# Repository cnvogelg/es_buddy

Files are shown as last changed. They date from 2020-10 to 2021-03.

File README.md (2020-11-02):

# es_buddy - EuroShield Add On Boards

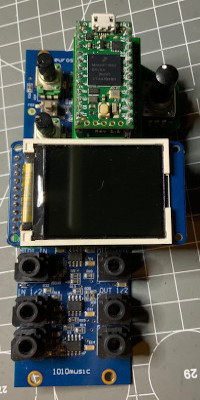
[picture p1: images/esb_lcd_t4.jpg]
esb_lcd_t4 Teensy 4.0 with LCD
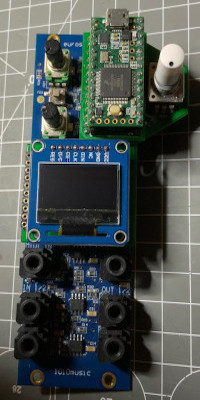
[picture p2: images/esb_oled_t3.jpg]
esb_oled_t3 Teensy 3.2 with OLED
 

EuroShield Buddy PCB Boards and Arduino Library.

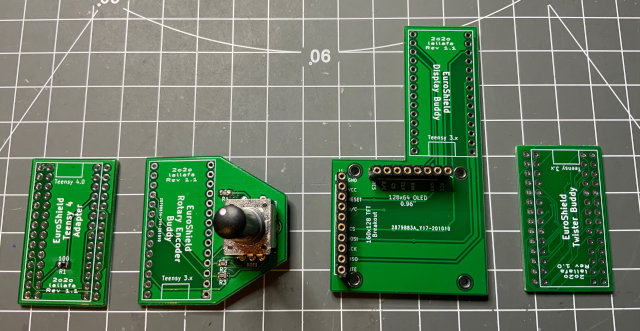
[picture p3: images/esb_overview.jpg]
esb_overview The ES Buddy Board Gallery


  - [Teensy 4.0 Adapter](#teensy-40-adapter)
  - [Rotary Encoder Buddy Board](#rotary-encoder-buddy-board)
  - [LCD/OLED Display Buddy Board](#lcdoled-display-buddy-board)
  - [Twister Buddy Board](#twister-buddy-board)

You can combine these boards as you like.

Licensed by Creative Commons Attribution Share Alike 4.0 International

## Teensy 4.0 Adapter

Version: 1.1

This little adapter board allows to use a Teensy 4.0 board on your EuroShield 1 (short ES) eurorack module.

This is the required re-routing of the Pins:

| Teensy 3.x / EuroShield Pin | Teensy 4.x Pin | Description |
|---|---|---|
| GND | GND | |
| 0 | 0 | Midi IN |
| 1 | 1 | Midi Out |
| 2 | 2 | Button on ES and on Rotary Encoder |
| 3 | 3 | LED 1 |
| 4 | 4 | LED 2 |
| 5 | 5 | LED 2 |
| 6 | 6 | LED 3 |
| 7 | 11 | SPI MOSI |
| 8 | 9 | Display Reset |
| 9 | 21 | Audio BCLK |
| 10 | 10 | SPI CS |
| 11 | 23 | Audio MCLK - A 100 Ohm Resistor is required here! |
| 12 | 12 | SPI MISO |

| Teensy 3.x / EuroShield Pin | Teensy 4.x Pin | Description |
|---|---|---|
| VIN | VIN | |
| AGND | AGND | |
| 3.3V | 3.3V | |
| 23 | 20 | Audio LRCLK |
| 22 | 7 | Audio TX DIN |
| 21 | 15 | Lo Pot on ES |
| 20 | 14 | Hi Pot on ES |
| 19 | 19 | I2C SCL |
| 18 | 18 | I2C SDA |
| 17 | 17 | Rotary Encoder A |
| 16 | 16 | Rotary Encoder B |
| 15 | 22 | Display CMD/Data |
| 14 | 13 | SPI SCK |
| 13 | 8 | Audio RX DOUT |

All Pins are direclty connected expect Audio MCLK is connected via
a 100 Ohm resistor.

## Rotary Encoder Buddy Board

Version: 1.1

Add a rotary encoder with button to your Euroshield.

### BOM

| Symbol | Part | Description | Mouser No. |
|---|---|---|---|
| ROT1 | PEC12R-3220F-S0024 | Bourns Rotary Encoder | 652-PEC12R3220FS0024 |
| R1-R3 | SMD 0805 10k | 10k Resistor | 71-CRCW080510K0FKEAC |

## LCD/OLED Display Buddy Board

Version: 1.1

Add an SPI LCD or OLED display to your EuroShield. While the OLED with 
128 x 64 fits nicely into the form factor of the shield, the LCD is wider
and offers 160 x 128 colored pixels.

The LCD has the following parameters:

 - 160 x 128 color TFT LCD 1.8 Inch
 - SPI
 - ST 7735 Controller

| LCD Pin | Teensy 3.2 Pin | Description |
| --- | --- | --- |
| 1 | GND | GND |
| 2 | 3.3V | 3.3V |
| 3 | 8  | Display Reset |
| 4 | 15 | Display Cmd/Data |
| 5 | -  | N/A |
| 6 | 10 | SPI CS |
| 7 | 7  | SPI MOSI |
| 8 | 14 | SPI SCK |
| 9 | 12 | SPI MISO |
| 10 | 3.3V | Display Light |

I use an Adafruit 1.8" Color TFT LCD display with MicroSD Card Breakout (358)

The OLED has the following parameters:

- 128 x 64 monochrome OLED 0.96 Inch
- SPI
- SSD 1306 Controller

| OLED Pin | Teensy 3.2 Pin | Description |
| --- | --- | --- |
| 1 | 3.3V | 3.3V |
| 2 | GND | GND |
| 3 | -  | N/A|
| 4 | 7  | SPI MOSI |
| 5 | 14 | SPI SCK |
| 6 | 10 | SPI CS |
| 7 | 15 | Display Cmd/Data |
| 8 | 8  | Display Reset |

## Twister Buddy Board

Version: 1.0

Turn the Teensy around so that the USB connector points upwards and 
a connected USB cable gets out of the way and does not obstruct the display.

# Build Instructions

If you want to build the full stack of buddy boards:

1. Start with the display board and solder extra long header pins

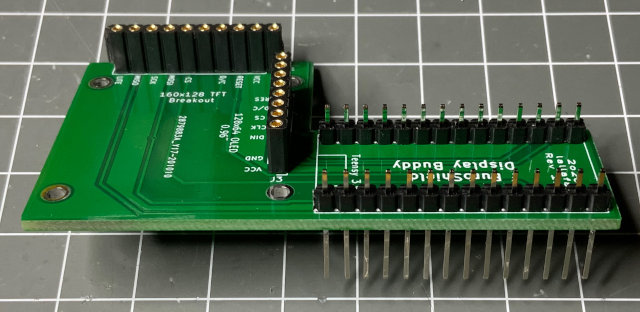
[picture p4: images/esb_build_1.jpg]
esb_build_1 Start with Display
  

2. First populate the rotary encoder board (resistors and the encoder) and 
  then solder the board below the display board

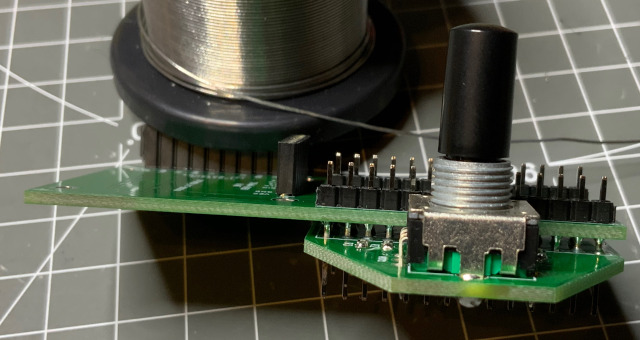
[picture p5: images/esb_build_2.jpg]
esb_build_2 Stack Rotary Encoder below
  

3. Prepare the Twister Board by adding headers to one side for a Teensy 4.0
  setup or a female connector for a Teensy 3.2. If you want to 
  use a Teensy 4.0 then add a female connector to the Teensy 4.0 side of the
  adapter:

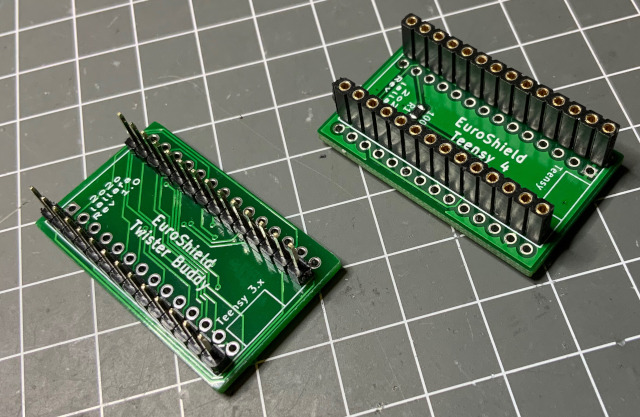
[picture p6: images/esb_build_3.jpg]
esb_build_3 Stack Rotary Encoder below
  

4. Solder the prepared Twister Board on top of the Display Board. Make sure
  that the Teensy USB port on the top side points upwards:

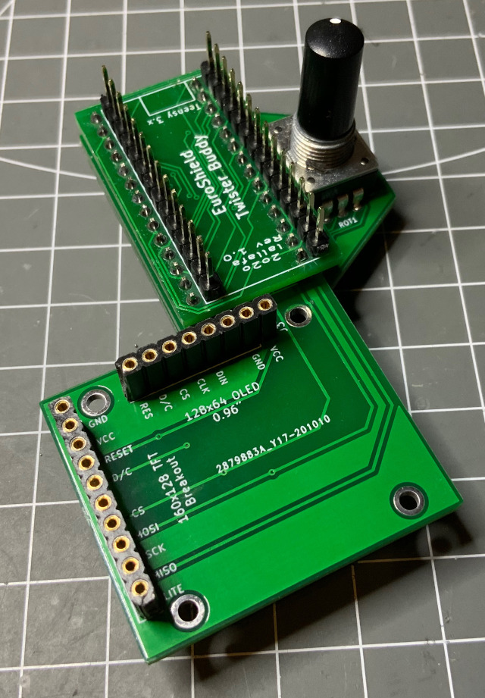
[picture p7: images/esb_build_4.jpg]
esb_build_4 Add Twister Board
  

5. For a Teensy 4.0 finally solder the Teensy 4.0 adapter board on top of
  the Twister Board. Note: make sure to add some space between the boards
  so that the Teensy 4.0 female connector pins do not touch the Display
  Board pins! Here a both variants: Teensy 4.0 and Teensy 3.2 boards

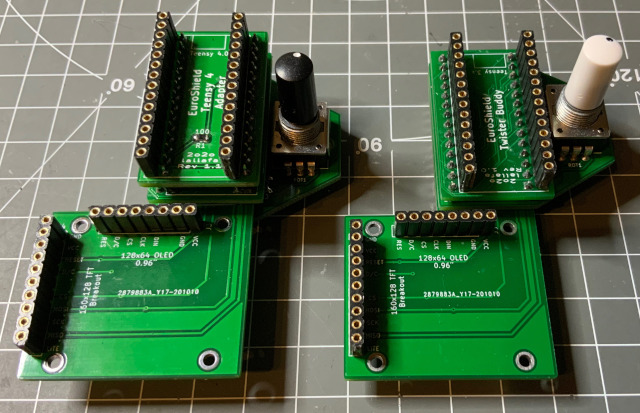
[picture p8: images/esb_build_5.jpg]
esb_build_5 Both Teensy 4.0 and Teensy 3.2 Board
  

6. Finally add either a LCD or OLED display. Both display types work with 
  both Teensy CPUs.

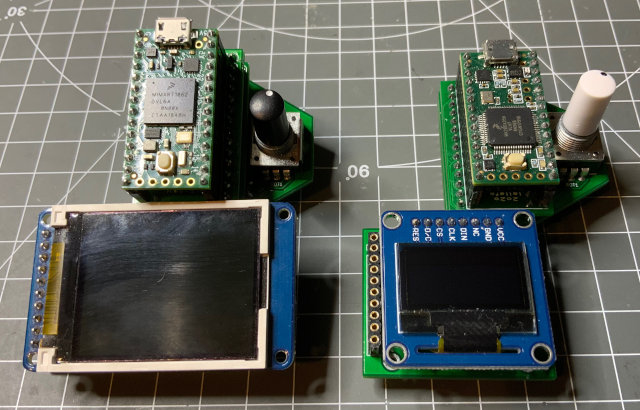
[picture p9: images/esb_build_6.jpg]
esb_build_6 Add LCD or OLED Display


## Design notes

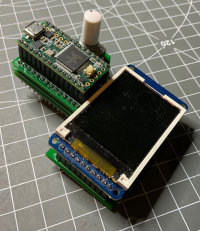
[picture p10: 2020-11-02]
images/esb_lcd_t3.jpg

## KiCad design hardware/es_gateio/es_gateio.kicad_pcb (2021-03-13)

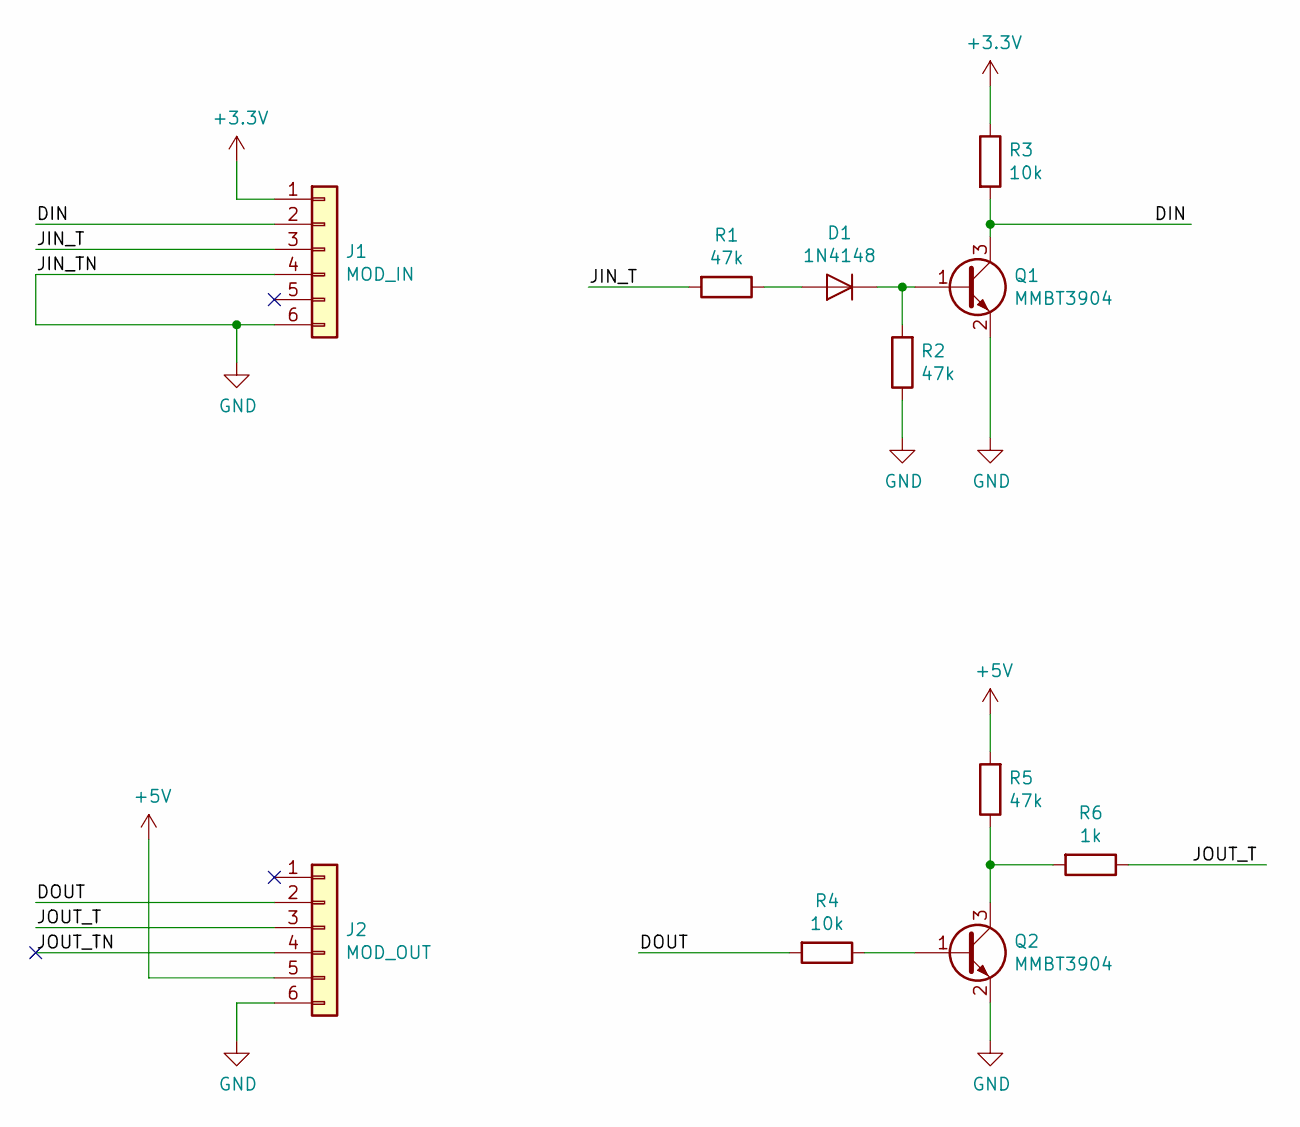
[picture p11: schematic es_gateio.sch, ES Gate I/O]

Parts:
D1: 1N4148; D_MiniMELF
J1: MOD_IN; PinHeader_2x03_P2.54mm_Vertical
J2: MOD_OUT; PinHeader_2x03_P2.54mm_Vertical
Q1, Q2: MMBT3904; SOT-23
R1, R2, R5: 47k; R_0805_2012Metric_Pad1.15x1.40mm_HandSolder
R3, R4: 10k; R_0805_2012Metric_Pad1.15x1.40mm_HandSolder
R6: 1k; R_0805_2012Metric_Pad1.15x1.40mm_HandSolder

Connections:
+3V3: J1.1, R3.1
+5V: J2.5, R5.2
/DIN: J1.2, Q1.3 (C), R3.2
/DOUT: J2.2, R4.2
/JIN_T: J1.3, R1.2
/JOUT_T: J2.3, R6.1
/JOUT_TN: J2.4
GND: J1.4, J1.6, J2.6, Q1.2 (E), Q2.2 (E), R2.1
unnamed: D1.1 (K), Q1.1 (B), R2.2
unnamed: D1.2 (A), R1.1
unnamed: Q2.1 (B), R4.1
unnamed: Q2.3 (C), R5.1, R6.2

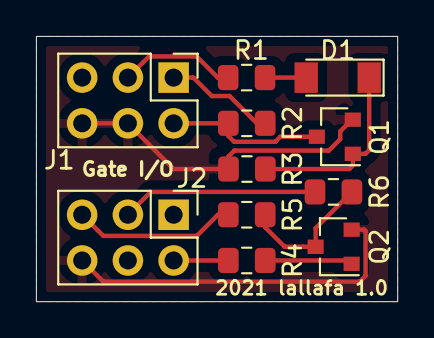
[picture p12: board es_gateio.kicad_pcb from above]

Board: 2 copper layers, 20.1 x 14.7 mm, 11 parts (0 on the bottom side), 11 nets.

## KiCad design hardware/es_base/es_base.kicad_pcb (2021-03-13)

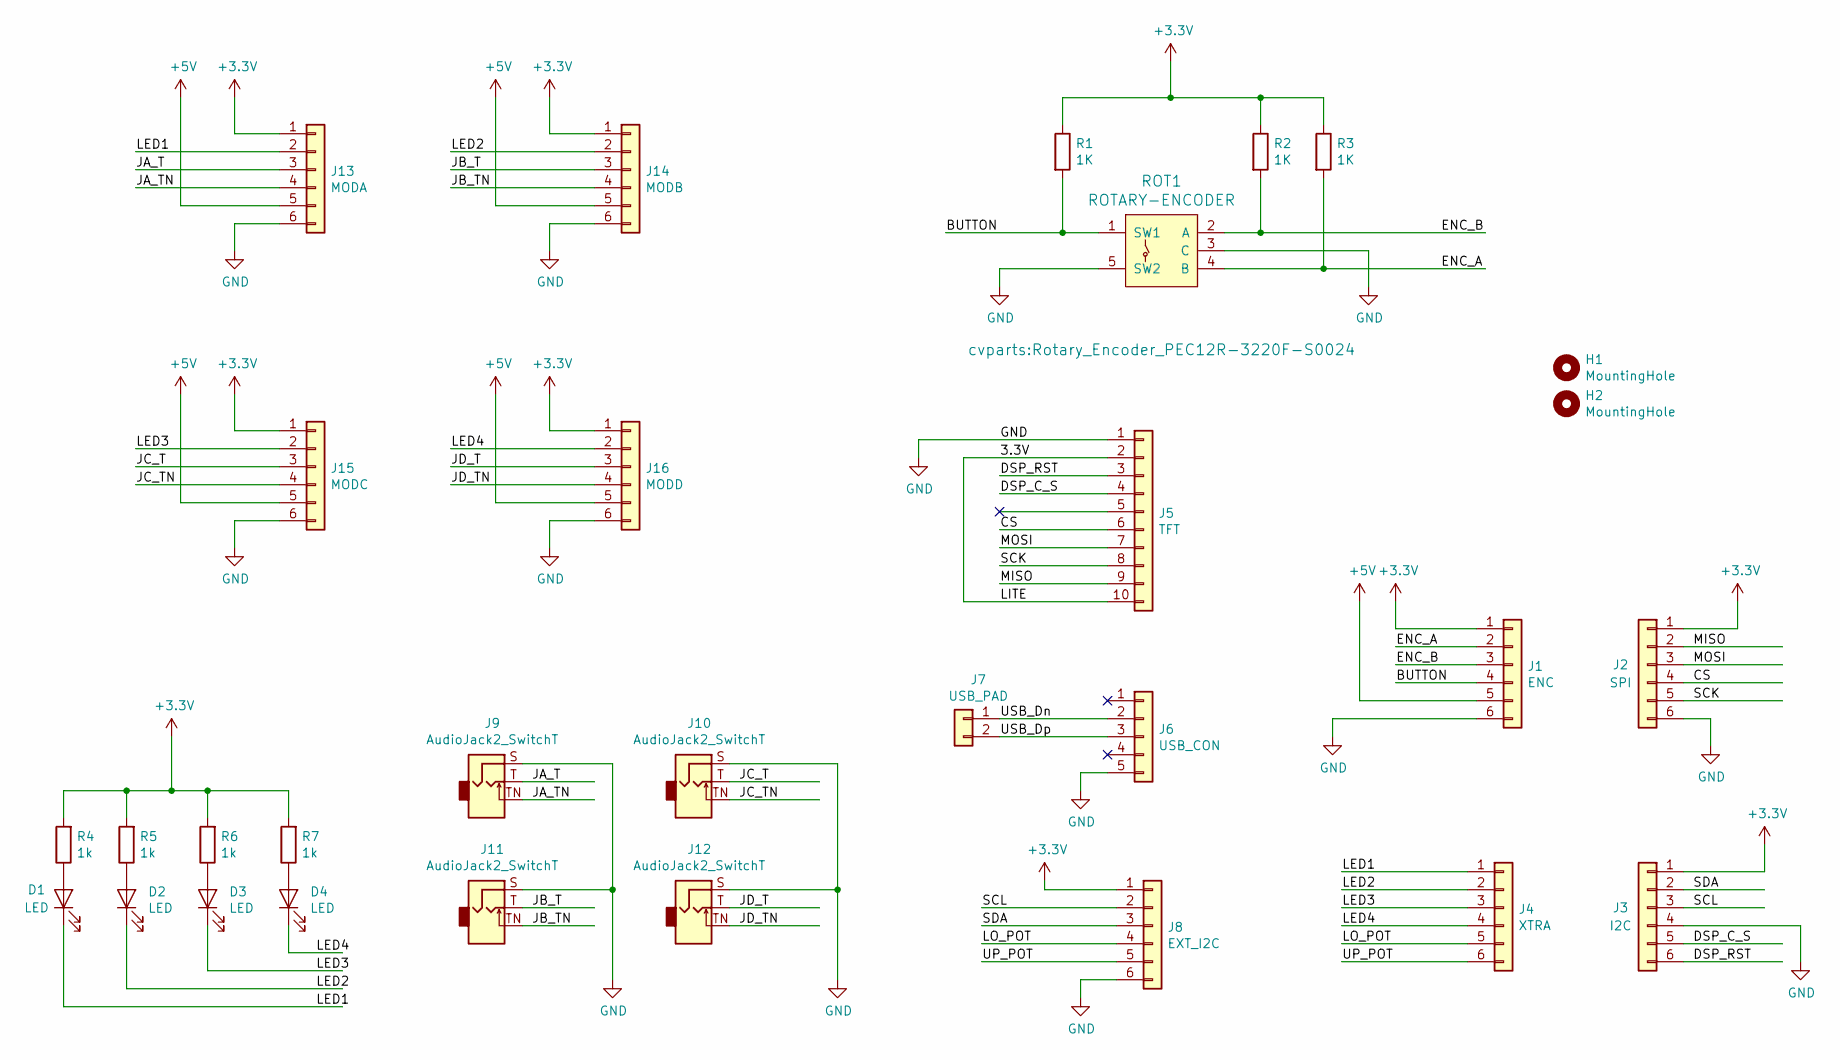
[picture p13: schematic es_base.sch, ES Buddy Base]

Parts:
D1, D2, D3, D4: LED; LED_D3.0mm
H1, H2: MountingHole; MountingHole_3.2mm_M3_ISO14580_Pad
J1: ENC; PinHeader_1x06_P2.54mm_Vertical
J2: SPI; PinHeader_1x06_P2.54mm_Vertical
J3: I2C; PinHeader_1x06_P2.54mm_Vertical
J4: XTRA; PinHeader_1x06_P2.54mm_Vertical
J5: TFT; PinHeader_1x10_P2.54mm_Vertical
J6: USB_CON; PinHeader_1x05_P2.54mm_Vertical
J7: USB_PAD; PinHeader_1x02_P2.54mm_Vertical
J8: EXT_I2C; PinHeader_2x03_P2.54mm_Vertical
J9, J10, J11, J12: AudioJack2_SwitchT; Jack_3.5mm_QingPu_WQP-PJ398SM_Vertical_CircularHoles
J13: MODA; PinHeader_2x03_P2.54mm_Vertical
J14: MODB; PinHeader_2x03_P2.54mm_Vertical
J15: MODC; PinHeader_2x03_P2.54mm_Vertical
J16: MODD; PinHeader_2x03_P2.54mm_Vertical
R1, R2, R3: 1K; R_0805_2012Metric_Pad1.15x1.40mm_HandSolder
R4, R5, R6, R7: 1k; R_0805_2012Metric_Pad1.15x1.40mm_HandSolder
ROT1: ROTARY-ENCODER; Rotary_Encoder_PEC12R-3220F-S0024

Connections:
+3V3: J1.1, J2.1, J3.1, J8.1, J13.1, J14.1, J15.1, J16.1, R1.1, R2.1, R3.1, R4.2, R5.2, R6.2, R7.2
+5V: J1.5, J13.5, J14.5, J15.5, J16.5
/3.3V: J5.2, J5.10
/BUTTON: J1.4, R1.2, ROT1.1 (SW1)
/CS: J2.4, J5.6
/DSP_C_S: J3.5, J5.4
/DSP_RST: J3.6, J5.3
/ENC_A: J1.2, R3.2, ROT1.4 (B)
/ENC_B: J1.3, R2.2, ROT1.2 (A)
/JA_T: J9.T, J13.3
/JA_TN: J9.TN, J13.4
/JB_T: J11.T, J14.3
/JB_TN: J11.TN, J14.4
/JC_T: J10.T, J15.3
/JC_TN: J10.TN, J15.4
/JD_T: J12.T, J16.3
/JD_TN: J12.TN, J16.4
/LED1: D1.1 (K), J4.1, J13.2
/LED2: D2.1 (K), J4.2, J14.2
/LED3: D3.1 (K), J4.3, J15.2
/LED4: D4.1 (K), J4.4, J16.2
/LO_POT: J4.5, J8.4
/MISO: J2.2, J5.9
/MOSI: J2.3, J5.7
/SCK: J2.5, J5.8
/SCL: J3.3, J8.2
/SDA: J3.2, J8.3
/UP_POT: J4.6, J8.5
/USB_Dn: J6.2, J7.1
/USB_Dp: J6.3, J7.2
GND: J1.6, J2.6, J3.4, J5.1, J6.5, J8.6, J9.S, J10.S, J11.S, J12.S, J13.6, J14.6, J15.6, J16.6, ROT1.3 (C), ROT1.5 (SW2)
unnamed: D1.2 (A), R4.1
unnamed: D2.2 (A), R5.1
unnamed: D3.2 (A), R6.1
unnamed: D4.2 (A), R7.1

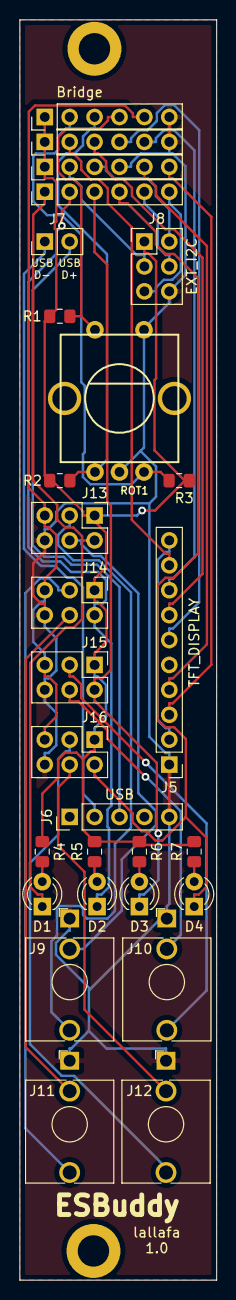
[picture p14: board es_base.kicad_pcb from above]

Board: 2 copper layers, 20.1 x 128.5 mm, 30 parts (0 on the bottom side), 35 nets.

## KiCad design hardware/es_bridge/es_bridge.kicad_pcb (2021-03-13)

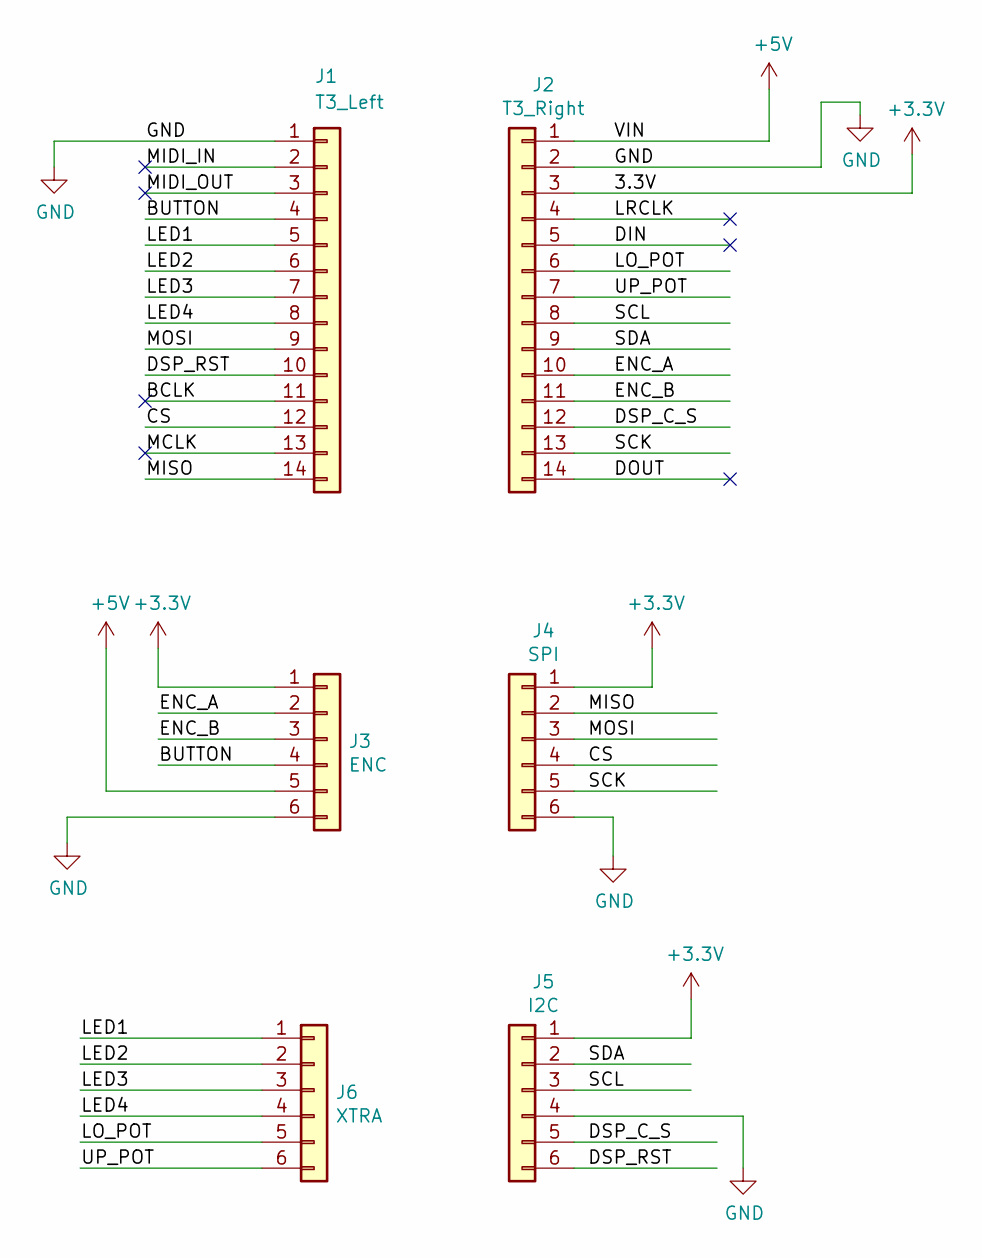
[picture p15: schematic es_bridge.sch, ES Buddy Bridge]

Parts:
J1: T3_Left; PinHeader_1x14_P2.54mm_Vertical_NoSilk
J2: T3_Right; PinHeader_1x14_P2.54mm_Vertical_NoSilk_NoPin1
J3: ENC; PinHeader_1x06_P2.54mm_Vertical
J4: SPI; PinHeader_1x06_P2.54mm_Vertical
J5: I2C; PinHeader_1x06_P2.54mm_Vertical
J6: XTRA; PinHeader_1x06_P2.54mm_Vertical

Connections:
+3V3: J2.3, J3.1, J4.1, J5.1
+5V: J2.1, J3.5
/BCLK: J1.11
/BUTTON: J1.4, J3.4
/CS: J1.12, J4.4
/DIN: J2.5
/DOUT: J2.14
/DSP_C_S: J2.12, J5.5
/DSP_RST: J1.10, J5.6
/ENC_A: J2.10, J3.2
/ENC_B: J2.11, J3.3
/LED1: J1.5, J6.1
/LED2: J1.6, J6.2
/LED3: J1.7, J6.3
/LED4: J1.8, J6.4
/LO_POT: J2.6, J6.5
/LRCLK: J2.4
/MCLK: J1.13
/MIDI_IN: J1.2
/MIDI_OUT: J1.3
/MISO: J1.14, J4.2
/MOSI: J1.9, J4.3
/SCK: J2.13, J4.5
/SCL: J2.8, J5.3
/SDA: J2.9, J5.2
/UP_POT: J2.7, J6.6
GND: J1.1, J2.2, J3.6, J4.6, J5.4

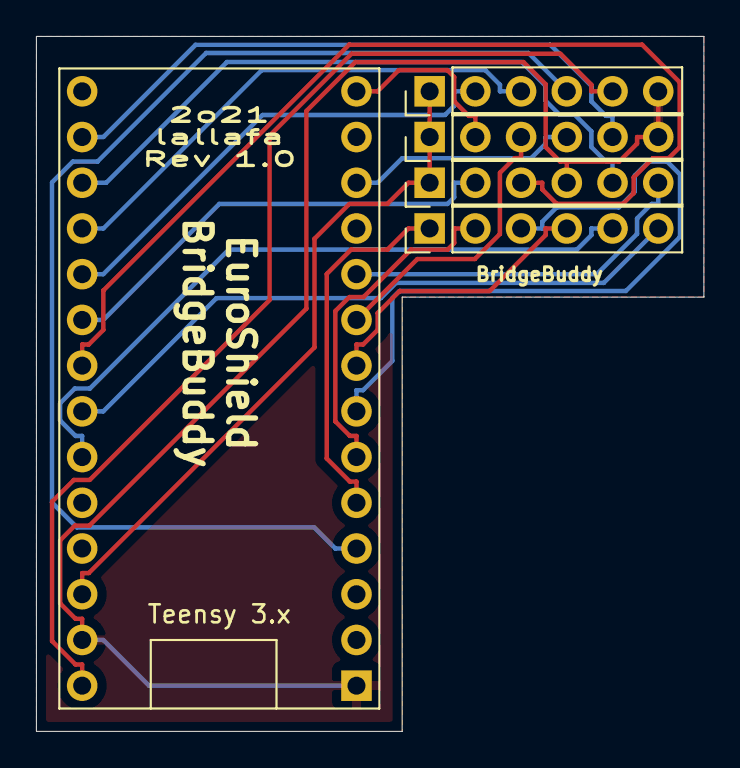
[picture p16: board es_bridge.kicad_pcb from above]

Board: 2 copper layers, 37.1 x 38.6 mm, 6 parts (0 on the bottom side), 20 nets.

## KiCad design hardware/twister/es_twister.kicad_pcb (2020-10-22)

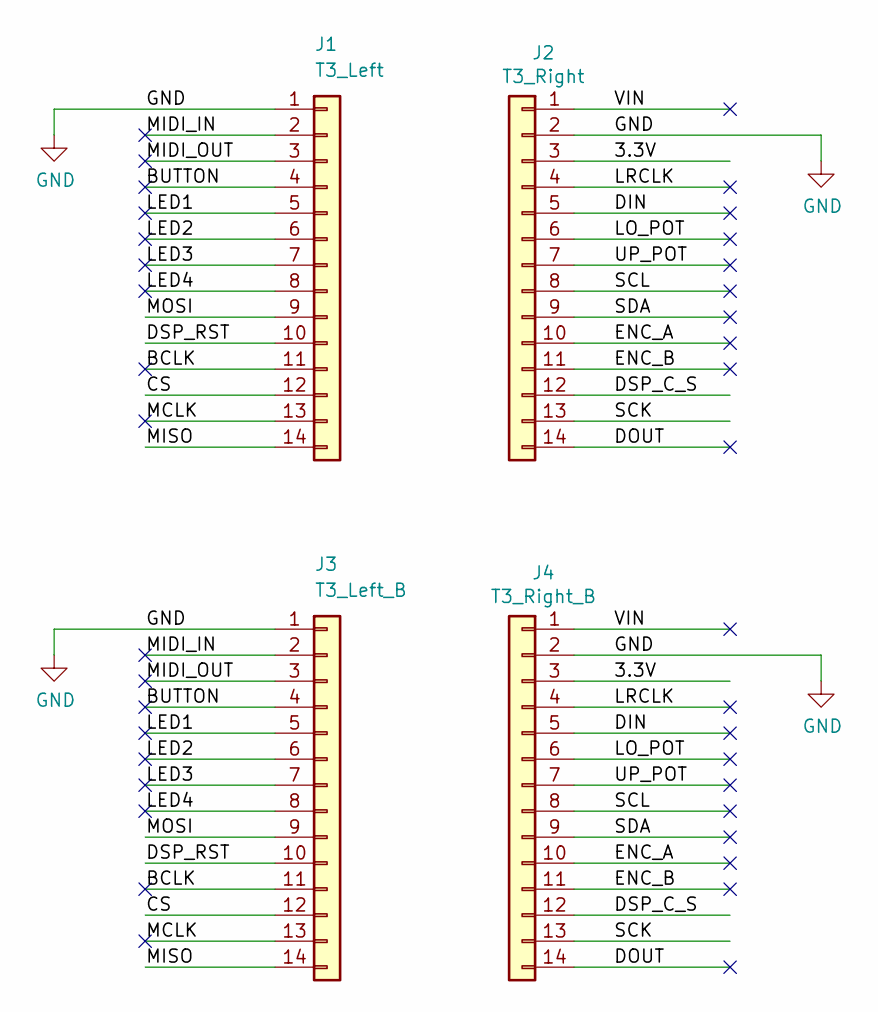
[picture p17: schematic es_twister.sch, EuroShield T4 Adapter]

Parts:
J1: T3_Left; PinHeader_1x14_P2.54mm_Vertical_NoSilk
J2: T3_Right; PinHeader_1x14_P2.54mm_Vertical_NoSilk_NoPin1
J3: T3_Left_B; PinHeader_1x14_P2.54mm_Vertical_NoSilk
J4: T3_Right_B; PinHeader_1x14_P2.54mm_Vertical_NoSilk_NoPin1

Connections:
/3.3V: J2.3, J4.3
/BCLK: J1.11, J3.11
/BUTTON: J1.4, J3.4
/CS: J1.12, J3.12
/DIN: J2.5, J4.5
/DOUT: J2.14, J4.14
/DSP_C_S: J2.12, J4.12
/DSP_RST: J1.10, J3.10
/ENC_A: J2.10, J4.10
/ENC_B: J2.11, J4.11
/LED1: J1.5, J3.5
/LED2: J1.6, J3.6
/LED3: J1.7, J3.7
/LED4: J1.8, J3.8
/LO_POT: J2.6, J4.6
/LRCLK: J2.4, J4.4
/MCLK: J1.13, J3.13
/MIDI_IN: J1.2, J3.2
/MIDI_OUT: J1.3, J3.3
/MISO: J1.14, J3.14
/MOSI: J1.9, J3.9
/SCK: J2.13, J4.13
/SCL: J2.8, J4.8
/SDA: J2.9, J4.9
/UP_POT: J2.7, J4.7
/VIN: J2.1, J4.1
GND: J1.1, J2.2, J3.1, J4.2

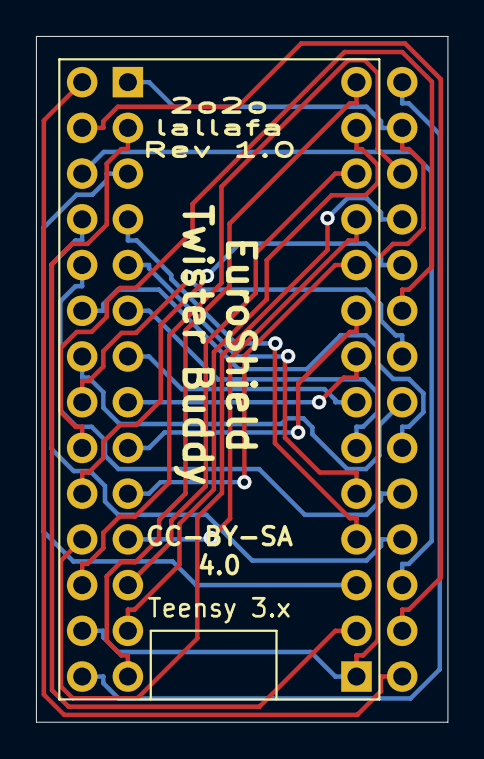
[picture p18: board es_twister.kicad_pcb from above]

Board: 2 copper layers, 22.9 x 38.1 mm, 4 parts (0 on the bottom side), 27 nets.

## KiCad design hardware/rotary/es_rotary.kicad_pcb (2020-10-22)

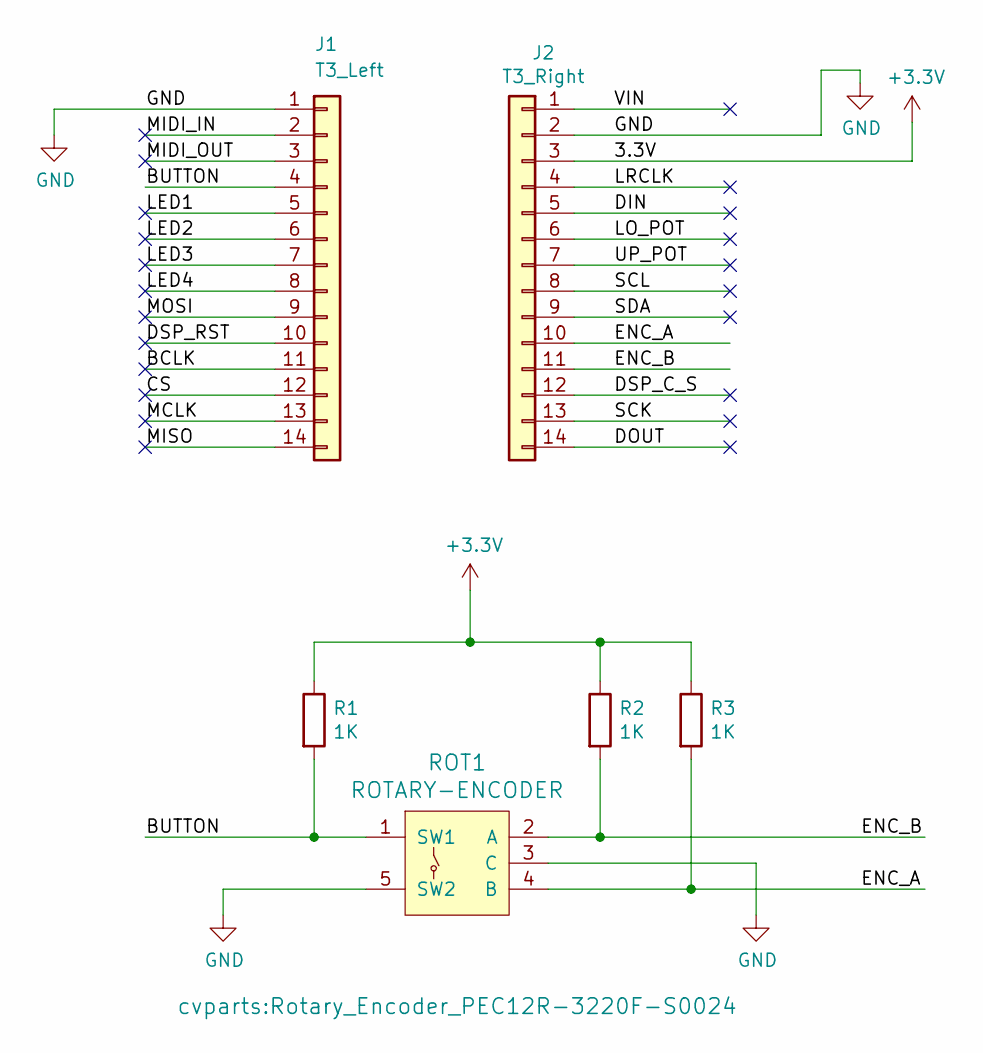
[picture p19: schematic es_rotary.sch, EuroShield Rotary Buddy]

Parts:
J1: T3_Left; PinHeader_1x14_P2.54mm_Vertical_NoSilk
J2: T3_Right; PinHeader_1x14_P2.54mm_Vertical_NoSilk_NoPin1
R1, R2, R3: 1K; R_0805_2012Metric_Pad1.15x1.40mm_HandSolder
ROT1: ROTARY-ENCODER; Rotary_Encoder_PEC12R-3220F-S0024

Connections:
+3V3: J2.3, R1.1, R2.1, R3.1
/BCLK: J1.11
/BUTTON: J1.4, R1.2, ROT1.1 (SW1)
/CS: J1.12
/DIN: J2.5
/DOUT: J2.14
/DSP_C_S: J2.12
/DSP_RST: J1.10
/ENC_A: J2.10, R3.2, ROT1.4 (B)
/ENC_B: J2.11, R2.2, ROT1.2 (A)
/LED1: J1.5
/LED2: J1.6
/LED3: J1.7
/LED4: J1.8
/LO_POT: J2.6
/LRCLK: J2.4
/MCLK: J1.13
/MIDI_IN: J1.2
/MIDI_OUT: J1.3
/MISO: J1.14
/MOSI: J1.9
/SCK: J2.13
/SCL: J2.8
/SDA: J2.9
/UP_POT: J2.7
/VIN: J2.1
GND: J1.1, J2.2, ROT1.3 (C), ROT1.5 (SW2)

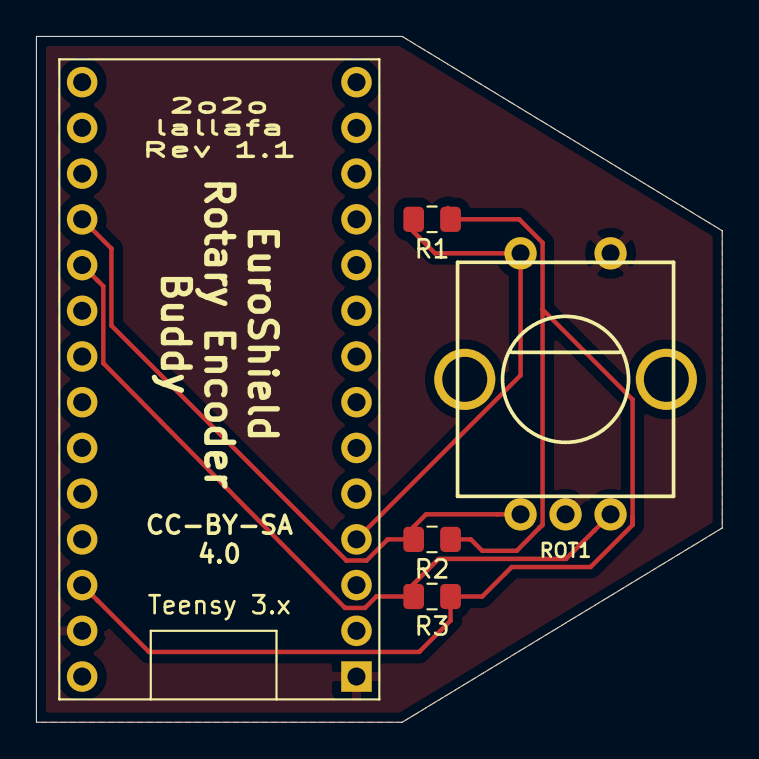
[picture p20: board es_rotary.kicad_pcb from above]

Board: 2 copper layers, 38.1 x 38.1 mm, 6 parts (0 on the bottom side), 5 nets.

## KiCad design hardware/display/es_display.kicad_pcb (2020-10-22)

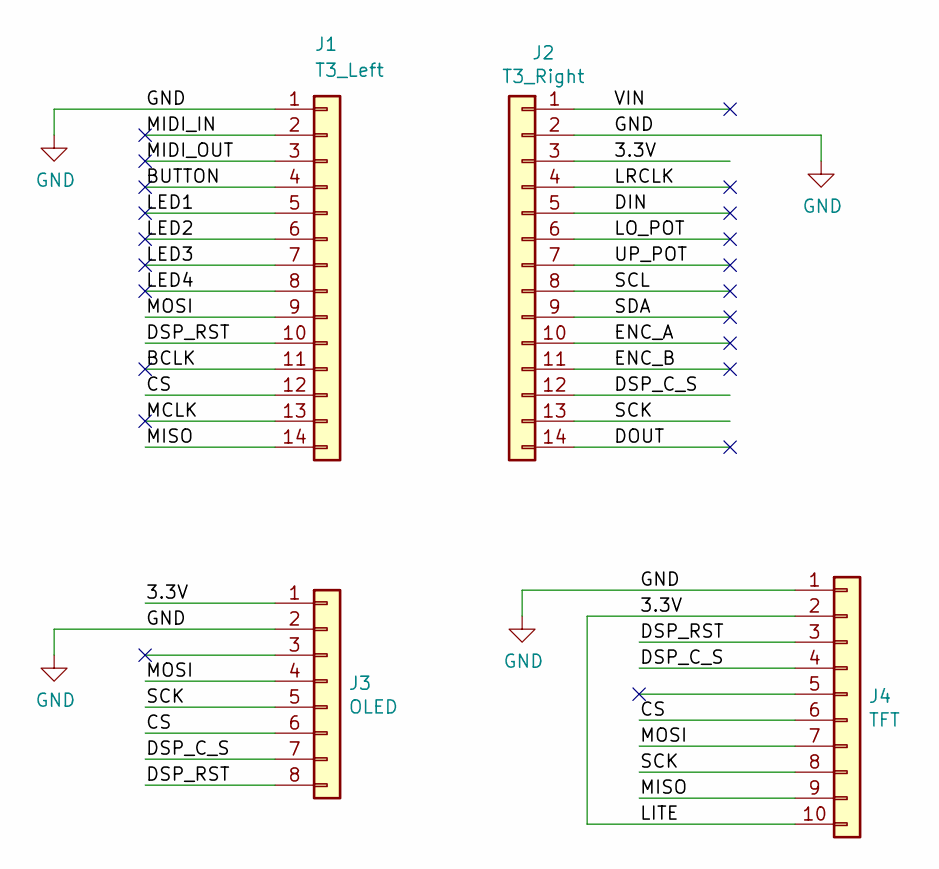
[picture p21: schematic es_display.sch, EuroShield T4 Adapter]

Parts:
J1: T3_Left; PinHeader_1x14_P2.54mm_Vertical_NoSilk
J2: T3_Right; PinHeader_1x14_P2.54mm_Vertical_NoSilk_NoPin1
J3: OLED; PinHeader_1x08_P2.54mm_Vertical
J4: TFT; PinHeader_1x10_P2.54mm_Vertical

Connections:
/3.3V: J2.3, J3.1, J4.2, J4.10
/BCLK: J1.11
/BUTTON: J1.4
/CS: J1.12, J3.6, J4.6
/DIN: J2.5
/DOUT: J2.14
/DSP_C_S: J2.12, J3.7, J4.4
/DSP_RST: J1.10, J3.8, J4.3
/ENC_A: J2.10
/ENC_B: J2.11
/LED1: J1.5
/LED2: J1.6
/LED3: J1.7
/LED4: J1.8
/LO_POT: J2.6
/LRCLK: J2.4
/MCLK: J1.13
/MIDI_IN: J1.2
/MIDI_OUT: J1.3
/MISO: J1.14, J4.9
/MOSI: J1.9, J3.4, J4.7
/SCK: J2.13, J3.5, J4.8
/SCL: J2.8
/SDA: J2.9
/UP_POT: J2.7
/VIN: J2.1
GND: J1.1, J2.2, J3.2, J4.1

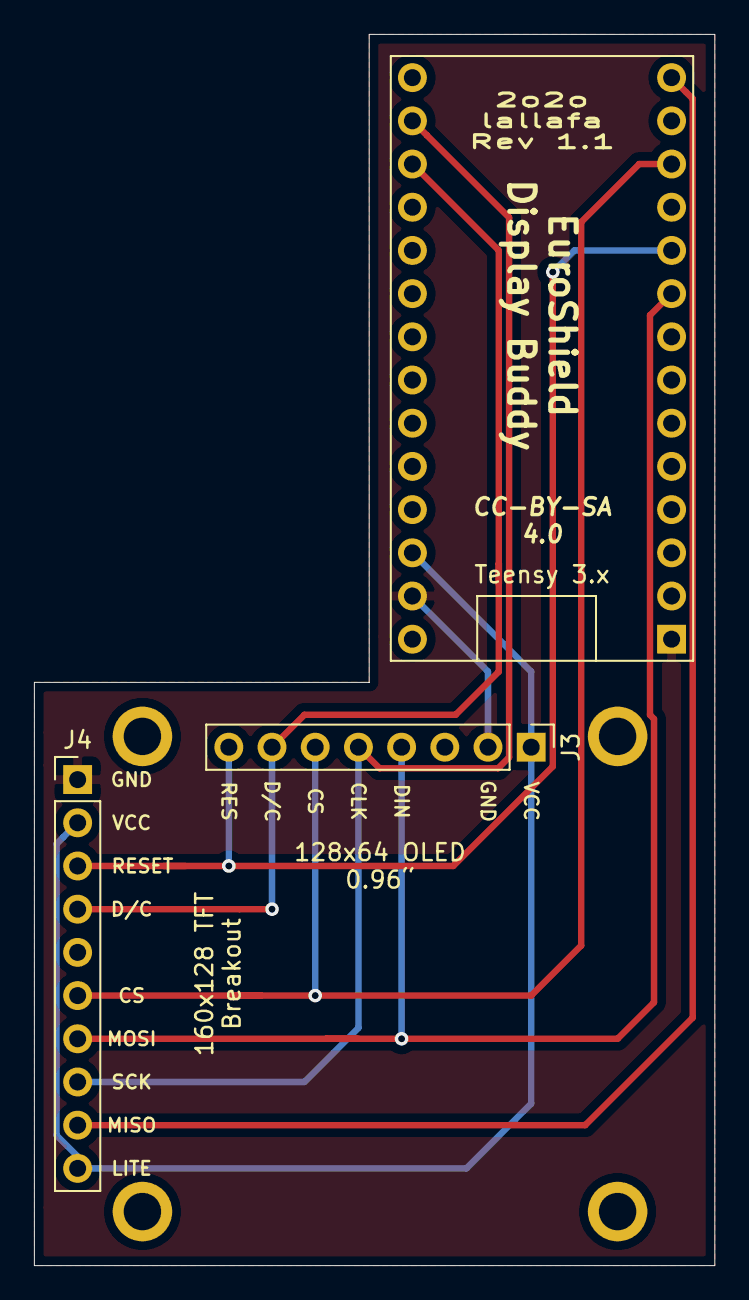
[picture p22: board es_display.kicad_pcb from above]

Board: 2 copper layers, 40.0 x 72.4 mm, 8 parts (0 on the bottom side), 8 nets.

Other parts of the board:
Pad1, Pad2, Pad3, Pad4: MountingHole_2.2mm_M2_ISO7380_Pad

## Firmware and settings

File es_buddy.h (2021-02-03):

#ifndef ES_BUDDY_H
#define ES_BUDDY_H

#include <Arduino.h>
#include <Audio.h>
#include <Encoder.h>
#include <Bounce.h>

#include "esb_tinyui.h"

// TFT Support
#ifdef ES_HAVE_TFT
#include <ST7735_t3.h>
#endif
// OLED Support
#ifdef ES_HAVE_OLED
#include <Adafruit_GFX.h>
#include <Adafruit_SSD1306.h>

#ifndef ES_OLED_WIDTH
#define ES_OLED_WIDTH 128
#endif
#ifndef ES_OLED_HEIGHT
#define ES_OLED_HEIGHT 64
#endif

#endif

// ----- EuroShield Pin Defitions

// Teensy 4.0
#if defined(__IMXRT1062__)

#define ES_DISPLAY_MISO_PIN     12
#define ES_DISPLAY_MOSI_PIN     11
#define ES_DISPLAY_SCK_PIN      13
#define ES_DISPLAY_DC_PIN       22
#define ES_DISPLAY_CS_PIN       10
#define ES_DISPLAY_RST_PIN      9

#define ES_POT_LO_PIN           15
#define ES_POT_UP_PIN           14

// Teensy 3.2
#elif defined(__MK20DX256__)

#define ES_DISPLAY_MISO_PIN     12
#define ES_DISPLAY_MOSI_PIN     7
#define ES_DISPLAY_SCK_PIN      14
#define ES_DISPLAY_DC_PIN       15
#define ES_DISPLAY_CS_PIN       10
#define ES_DISPLAY_RST_PIN      8

#define ES_POT_LO_PIN           21
#define ES_POT_UP_PIN           20

// Unsupported Teensy
#else
#error Unknown Teensy
#endif

// common defs
#define ES_ROTARY_ENCA_PIN      16
#define ES_ROTARY_ENCB_PIN      17

#define ES_BUTTON_PIN           2
#define ES_LED1_PIN             3
#define ES_LED2_PIN             4
#define ES_LED3_PIN             5
#define ES_LED4_PIN             6

#define ES_MIDI_IN_PIN          0
#define ES_MIDI_OUT_PIN         1


enum class ButtonState { ENABLE, DISABLE, NONE };

class ESBuddy : public Print, public EventSource
{
public:
    ESBuddy();

    void init();

    AudioStream &audioInput() { return _audioInput; }
    AudioStream &audioOutput() { return _audioOutput; }

    int encoderRead();
    ButtonState buttonRead();
    bool isButtonDown() { buttonRead(); return _buttonDown; }

    int potLoReadRaw() { return analogRead(ES_POT_LO_PIN); }
    int potUpReadRaw() { return analogRead(ES_POT_UP_PIN); }

    float potLoRead() { return analogRead(ES_POT_LO_PIN) / 1024.f; }
    float potUpRead() { return analogRead(ES_POT_UP_PIN) / 1024.f; }

    void ledWrite(int num, bool on) { digitalWrite(led_pins[num], on ? HIGH : LOW); }
    void ledBarWrite(int val);

    void dumpState(Print &printer);
    void dumpAudioState(Print &printer);

    // Print support
    virtual size_t write(uint8_t c)  { return Serial.write(c); }
    virtual size_t write(const uint8_t *buffer, size_t size) {
        return Serial.write(buffer, size);
    }

    virtual bool pollEvent(Event &e);

private:
    AudioInputI2S          _audioInput;  
    AudioOutputI2S         _audioOutput;  
    AudioControlSGTL5000   _audioShield;

    Encoder                _encoder;
    int                    _encVal;
    Bounce                 _button;
    bool                   _buttonDown;  
    unsigned long          _pressStart;
    bool                   _buttonLong;
    bool                   _buttonExtraLong;

    const int led_pins[4] = {
        ES_LED1_PIN, ES_LED2_PIN, ES_LED3_PIN, ES_LED4_PIN
    };
};

#ifdef ES_HAVE_TFT

class ESBuddyTFT : public ESBuddy, public Display
{
public:
    static const int DISPLAY_WIDTH = 160;
    static const int DISPLAY_HEIGHT = 128;

    static const int FONT_WIDTH = 6;
    static const int FONT_HEIGHT = 8;

    ESBuddyTFT() : 
        ESBuddy(),
        _tftDisplay(
            ES_DISPLAY_CS_PIN,
            ES_DISPLAY_DC_PIN, 
            ES_DISPLAY_MOSI_PIN,
            ES_DISPLAY_SCK_PIN, 
            ES_DISPLAY_RST_PIN
        )
    {}

    void init()
    {
        ESBuddy::init();

        _tftDisplay.initR(INITR_BLACKTAB);
        _tftDisplay.setRotation(3);
        _tftDisplay.fillScreen(ST7735_BLACK);

        _penColor = ST7735_WHITE;
    }

    ST7735_t3 &display() { return _tftDisplay; }

    virtual void displayClear() { 
        _tftDisplay.useFrameBuffer(true);
        _tftDisplay.fillScreen(ST7735_BLACK);
        homeCursor();
    }
    virtual void displayUpdate() { _tftDisplay.updateScreen(); }

    virtual int getDisplayWidth() { return DISPLAY_WIDTH; }
    virtual int getDisplayHeight() { return DISPLAY_HEIGHT; }

    virtual void homeCursor() { _tftDisplay.setCursor(0,0); }
    virtual void setCursor(int col, int row) {
        _tftDisplay.setCursor(
            col * FONT_WIDTH,
            row * FONT_HEIGHT);
    }
    virtual void setCursorXY(int x, int y) {
        _tftDisplay.setCursor(x, y);
    }
    virtual int getMaxCursorCol() { return (DISPLAY_WIDTH / FONT_WIDTH)-1; }
    virtual int getMaxCursorRow() { return (DISPLAY_HEIGHT / FONT_HEIGHT)-1; }
    virtual Print &getPrint() { return *this; }

    virtual void setTextColor(uint16_t fg, uint16_t bg) {
        _tftDisplay.setTextColor(fg, bg);
    }
    virtual void setTextColor(uint16_t fg) {
        _tftDisplay.setTextColor(fg);
    }
    virtual void setTextScale(uint8_t sx, uint8_t sy) {
        _tftDisplay.setTextSize(sx, sy);
    }
    virtual int getTextSizeX() { return _tftDisplay.getTextSizeX(); }
    virtual int getTextSizeY() { return _tftDisplay.getTextSizeY(); }

    virtual int getFontWidth() { return FONT_WIDTH; }
    virtual int getFontHeight() { return FONT_HEIGHT; }

    // Print support
    virtual size_t write(uint8_t c)  { return _tftDisplay.write(c); }
    virtual size_t write(const uint8_t *buffer, size_t size) {
        return _tftDisplay.write(buffer, size);
    }

    // Drawable
    virtual void setColor(uint16_t color) { _penColor = color; }
    virtual void vline(int x, int y, int h) {
        _tftDisplay.drawFastVLine(x, y, h, _penColor);
    }
    virtual void hline(int x, int y, int w) {
        _tftDisplay.drawFastHLine(x, y, w, _penColor);
    }
    virtual void line(int x1, int y1, int x2, int y2) {
        _tftDisplay.drawLine(x1, y1, x2, y2, _penColor);
    }
    virtual void pixel(int x, int y) {
        _tftDisplay.drawPixel(x, y, _penColor);
    }
    virtual void fillRect(int x, int y, int w, int h)
    {
        _tftDisplay.fillRect(x, y, w, h, _penColor);
    }

    virtual void drawRect(int x, int y, int w, int h)
    {
        _tftDisplay.drawRect(x, y, w, h, _penColor);
    }

private:
    ST7735_t3 _tftDisplay;
    uint16_t  _penColor;
};
#endif // ES_HAVE_TFT
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

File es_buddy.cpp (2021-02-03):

#include "es_buddy.h"

const int myInput = AUDIO_INPUT_LINEIN;

ESBuddy::ESBuddy()
    : _encoder(ES_ROTARY_ENCB_PIN, ES_ROTARY_ENCA_PIN),
      _encVal(0),
      _button(ES_BUTTON_PIN, 5)
{}

void ESBuddy::init()
{
    pinMode(ES_BUTTON_PIN, INPUT);
    // setup LEDs
    pinMode(ES_LED1_PIN, OUTPUT);
    pinMode(ES_LED2_PIN, OUTPUT);
    pinMode(ES_LED3_PIN, OUTPUT);
    pinMode(ES_LED4_PIN, OUTPUT);

    // setup shield mixer
    _audioShield.enable();
    _audioShield.inputSelect(myInput);
    _audioShield.volume(0.82);
    _audioShield.adcHighPassFilterDisable();
    _audioShield.lineInLevel(0,0);
}

int ESBuddy::encoderRead()
{
    int val = _encoder.read();
    if(val == _encVal) {
        return 0;
    } else {
        int steps = (val - _encVal) / 4;
        _encVal += steps * 4;
        return steps;
    }
}

ButtonState ESBuddy::buttonRead() 
{ 
    _button.update();
    if(_button.risingEdge()) {
        _buttonDown = false;
        return ButtonState::DISABLE;
    } else if(_button.fallingEdge()) {
        _buttonDown = true;
        return ButtonState::ENABLE;
    } else {
        return ButtonState::NONE;
    }
}

bool ESBuddy::pollEvent(Event &e)
{
    // check button
    ButtonState state = buttonRead();
    if(state == ButtonState::ENABLE) {
        e.type = EventType::BUTTON_DOWN;
        _pressStart = millis();
        _buttonLong = false;
        _buttonExtraLong = false;
        return true;
    }
    else if(state == ButtonState::DISABLE) {
        if(_buttonExtraLong) {
            e.type = EventType::BUTTON_UP_EXTRA_LONG;
        } else if(_buttonLong) {
            e.type = EventType::BUTTON_UP_LONG;
        } else {
            e.type = EventType::BUTTON_UP;
        }
        return true;
    }

    // check long press
    if(_buttonDown) {
        unsigned long delta = millis() - _pressStart;
        if(delta > 500) {
            _buttonLong = true;
        }
        if(delta > 2000) {
            _buttonExtraLong = true;
        }
    }

    // check encoder
    int delta = encoderRead();
    if(delta < 0) {
        e.type = EventType::DEC_VALUE;
        e.value = -delta;
        return true;
    }
    else if(delta > 0) {
        e.type = EventType::INC_VALUE;
        e.value = delta;
        return true;
    }

    return false;
}

void ESBuddy::ledBarWrite(int val)
{
    digitalWrite(ES_LED1_PIN, (val & 1)== 1 ? HIGH : LOW);
    digitalWrite(ES_LED2_PIN, (val & 2)== 2 ? HIGH : LOW);
    digitalWrite(ES_LED3_PIN, (val & 4)== 4 ? HIGH : LOW);
    digitalWrite(ES_LED4_PIN, (val & 8)== 8 ? HIGH : LOW);
}

void ESBuddy::dumpState(Print &printer)
{
    printer.println("ESBuddy:");

    printer.print("  button=");
    ButtonState state = buttonRead();
    switch(state) {
        case ButtonState::NONE:
            printer.println("NONE");
            break;
        case ButtonState::ENABLE:
            printer.println("ENABLE");
            break;
        case ButtonState::DISABLE:
            printer.println("DISABLE");
            break;
    }

    printer.print("  potLo=");
    printer.print(potLoRead());
    printer.print("/");
    printer.println(potLoReadRaw());

    printer.print("  potUp=");
    printer.print(potUpRead());
    printer.print("/");
    printer.println(potUpReadRaw());

    printer.print("  encoder=");
    printer.println(encoderRead());
}

void ESBuddy::dumpAudioState(Print &printer)
{
    printer.println("AudioState:");
    printer.print("  proc=");
    printer.println(AudioProcessorUsage());
    printer.print("  max=");
    printer.println(AudioProcessorUsageMax());
}

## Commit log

2020-09-26 added t4 adapter
    [es_t4-B_Cu.gbr, es_t4-B_Mask.gbr, es_t4-B_Paste.gbr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]
2020-09-26 added display
    [es_display-B_Cu.gbr, es_display-B_Mask.gbr, es_display-B_Paste.gbr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]
2020-09-26 added rotary
    [es_rotary-B_Cu.gbr, es_rotary-B_Mask.gbr, es_rotary-B_Paste.gbr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]
2020-10-09 added t4 pin mapping
2020-10-09 updated rot and display to v1.1
    [es_display-B_Cu.gbr, es_display-B_Mask.gbr, es_display-B_Paste.gbr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]
2020-10-09 added twister
    [es_twister-B_Cu.gbr, es_twister-B_Mask.gbr, es_twister-B_Paste.gbr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]
2020-10-10 started Arduino lib
2020-10-22 set license: CC-BY-SA-4.0
    [es_display-B_Cu.gbr, es_display-B_Mask.gbr, es_display-B_Paste.gbr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]
2020-11-02 updated rotary gerbers
    [es_rotary-B_Cu.gbr, es_rotary-B_Mask.gbr, es_rotary-B_Paste.gbr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]
2020-11-26 introduced sample array
2021-02-03 fixed es audio setup
    [es_buddy.cpp, es_buddy.h]
2021-03-13 added new hardware: bridge, base board, and gateio
    [es_base-B_Cu.gbr, es_base-B_Mask.gbr, es_base-B_Paste.gbr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]
